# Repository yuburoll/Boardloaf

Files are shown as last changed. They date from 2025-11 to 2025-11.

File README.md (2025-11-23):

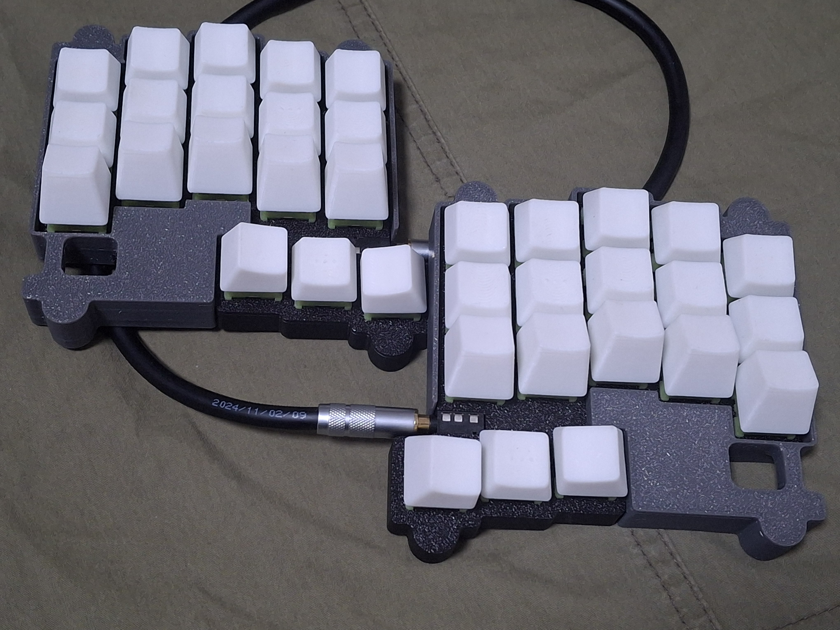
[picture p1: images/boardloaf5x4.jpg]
boardloafImage


# Boardloaf

36 key hotswappable split keyboard in 100x100 pcb

## Preparation

- 2x rp2040 zero (boards formly created by waveshare) (Approx. 4-8$)

- 2x Boardloaf PCB Boards (5 boards are 2$ on JLC w/o shipping cost)

- 1x printed case sets, which you want to make it (4$ for sandwitch, Approx. 12$ if you buy printed one)

- 36x diodes (Approx. 1$)

- (for V1) 32x M2x4 bolts, 16x M2x7 spacers (under 4mm radius) (Approx. 2$)

- (for V2) 16x M2x7 screws, flathead (can use M2x6 or M2x8) (Approx. 1$)

- 2x PJ320A 1/8(3.5mm) TRRS connector (Approx. 1$)

- 1x 1/8(3.5mm) TRRS cable (Approx. 2$, may TRS cable can take the place.)

- 36x MX Keyswitches & Keycaps & MX Hotswap Sockets (Maybe this cost varies too much. 10$ on average)

Approx. 26$-37$(w/o shipping cost) needed to build one.

## Build Guides

work in progress. sorry!

You can see the images in the folder, which uploaded for build guides. Especially you may see how to solder the controller board, because this uses surface mounting by castelated pins.

Images are captured with prototype version PCB, which is different from the current gerber. Current gerber has two "Jump when back side" jumper point on each side, to check which hand is on the position. You may see diode jumper on assembly image for the same role, and you don't need to jump via diodes if you jump jumpers correctly.

This uses [qmk](https://qmk.fm/) to build the firmware. Copy "boardloaf" folder which is in "firmware/qmk" directory to "qmk_firmware\keyboards" folder, and build it via qmk msys.

Or, simply flash uf2 in "uf2Examples" folder by changing rp2040 zero in dfu mode, which can be executed by holding boot button while plugging in usb c. Vial versions are also prepared.

## Licenses

miryoku keymap follows GNU GPL 2.0 license.

all other codes follow MIT license.

all designs and the hardware board follow CC BY-SA 4.0 license.

If you want to make a commercial product, it would be appreciated if you sponsor some bucks for me.

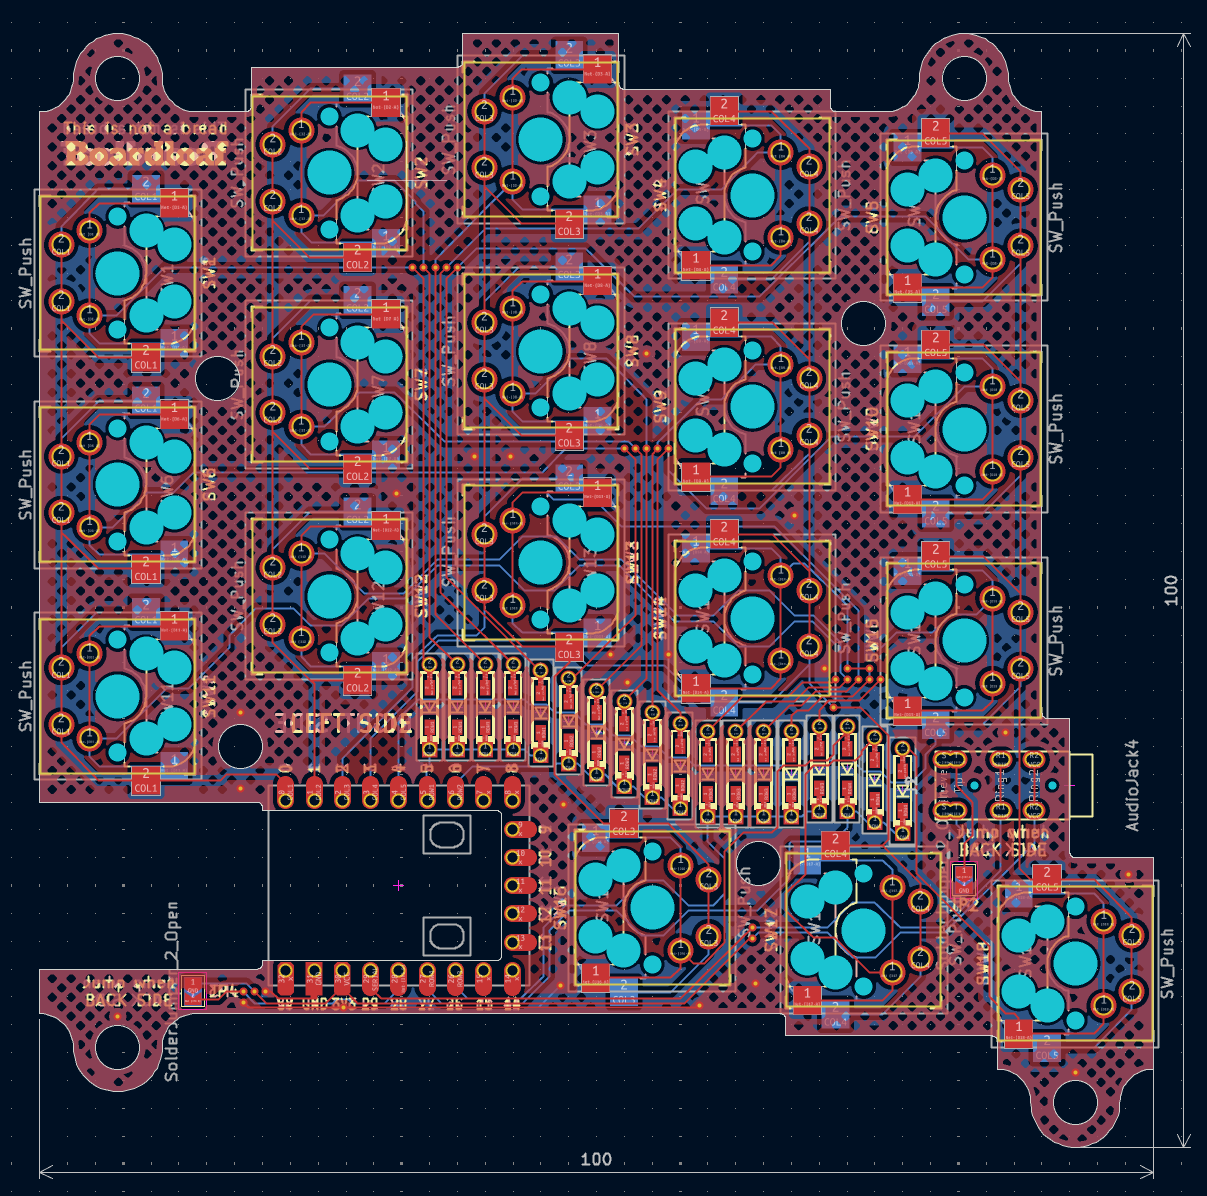
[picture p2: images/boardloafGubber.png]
boardloafGubber


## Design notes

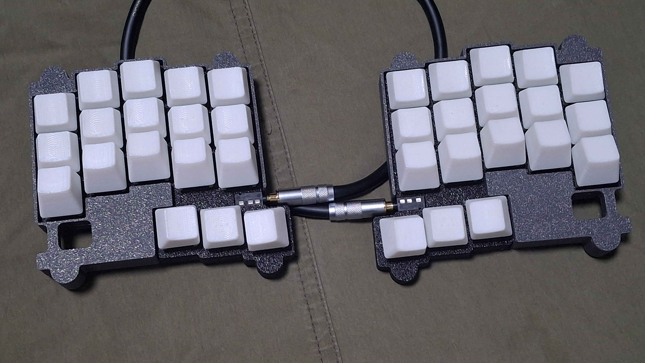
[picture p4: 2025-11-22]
images/boardloaf16x9.jpg

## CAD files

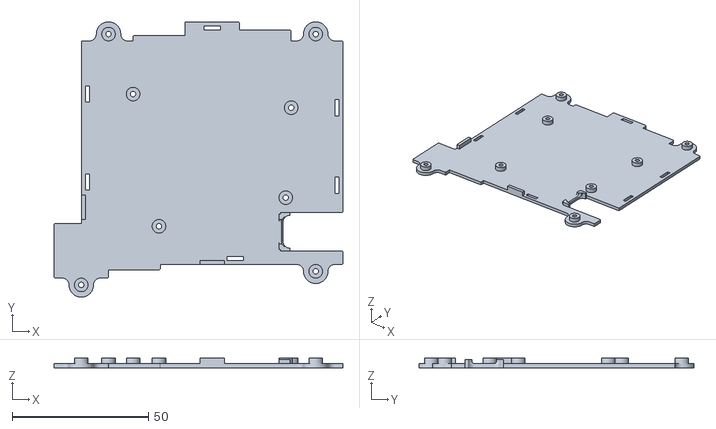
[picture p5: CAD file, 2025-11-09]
case/V2_3dp/BoardloafCaseV2_RDown.stl
106.0 x 101.0 x 3.50

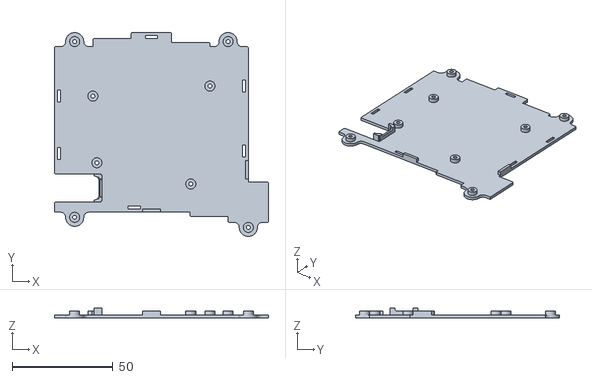
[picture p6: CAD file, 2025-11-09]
case/V2_3dp/BoardloafCaseV2_LDown.stl
106.0 x 101.0 x 5.00

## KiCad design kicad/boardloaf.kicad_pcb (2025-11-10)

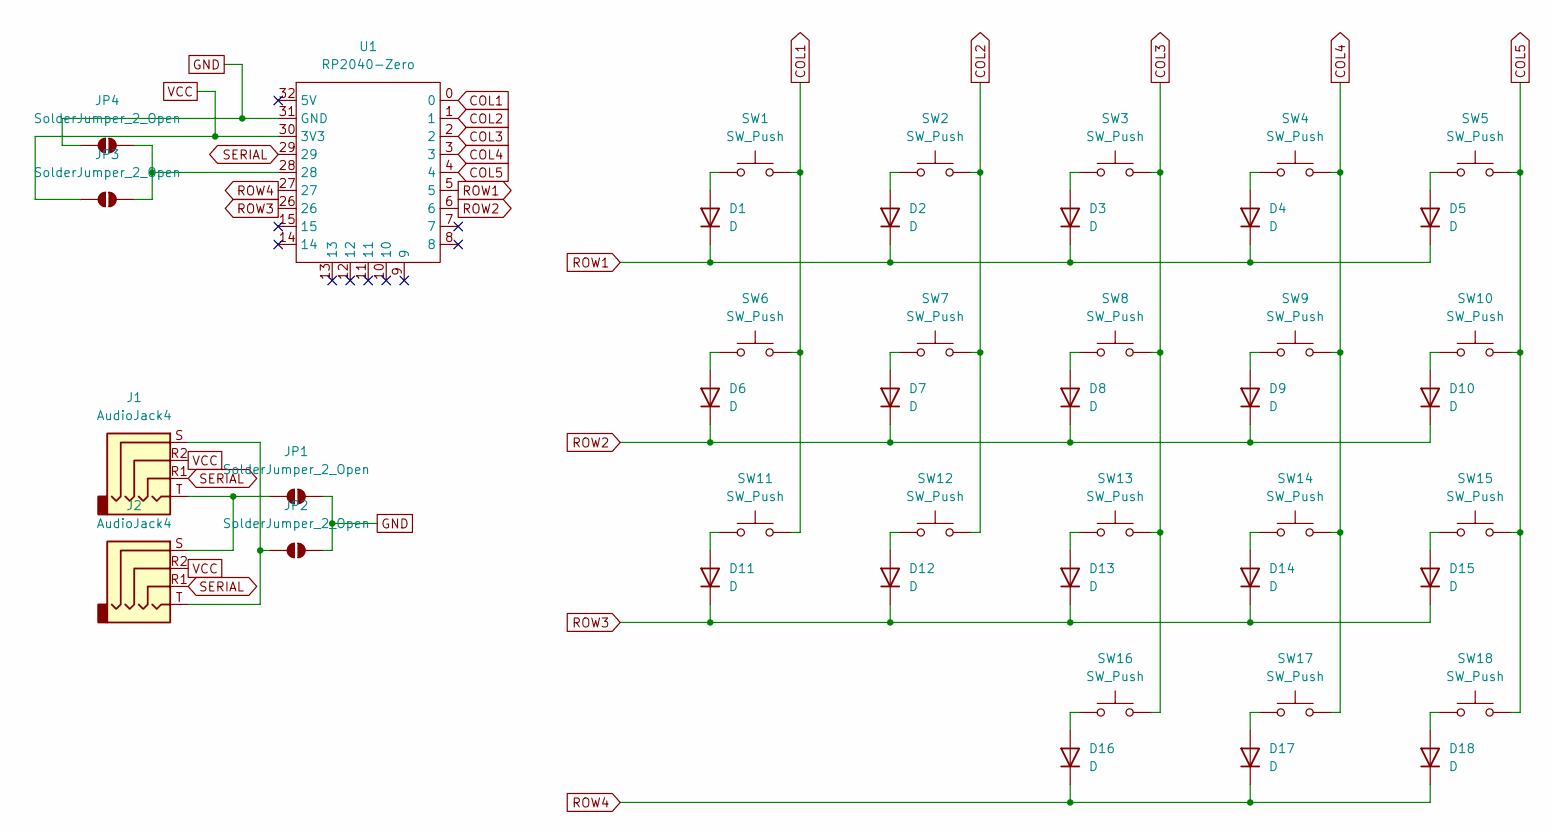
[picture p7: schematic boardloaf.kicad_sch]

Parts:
D1, D2, D3, D4, D5, D6, D7, D8, D9, D10, D11, D12, D13, D14, D15, D16, D17, D18: D
J1, J2: AudioJack4
JP1, JP2, JP3, JP4: SolderJumper_2_Open
SW1, SW2, SW3, SW4, SW5, SW6, SW7, SW8, SW9, SW10, SW11, SW12, SW13, SW14, SW15, SW16, SW17, SW18: SW_Push
U1: RP2040-Zero

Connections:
COL1: SW1.2, SW6.2, SW11.2, U1.0
COL2: SW2.2, SW7.2, SW12.2, U1.1
COL3: SW3.2, SW8.2, SW13.2, SW16.2, U1.2
COL4: SW4.2, SW9.2, SW14.2, SW17.2, U1.3
COL5: SW5.2, SW10.2, SW15.2, SW18.2, U1.4
GND: JP1.2 (B), JP2.2 (B), JP4.1 (A), U1.31 (GND)
unnamed: D1.2 (A), SW1.1
unnamed: D2.2 (A), SW2.1
unnamed: D3.2 (A), SW3.1
unnamed: D4.2 (A), SW4.1
unnamed: D5.2 (A), SW5.1
unnamed: D6.2 (A), SW6.1
unnamed: D7.2 (A), SW7.1
unnamed: D8.2 (A), SW8.1
unnamed: D9.2 (A), SW9.1
unnamed: D10.2 (A), SW10.1
unnamed: D11.2 (A), SW11.1
unnamed: D12.2 (A), SW12.1
unnamed: D13.2 (A), SW13.1
unnamed: D14.2 (A), SW14.1
unnamed: D15.2 (A), SW15.1
unnamed: D16.2 (A), SW16.1
unnamed: D17.2 (A), SW17.1
unnamed: D18.2 (A), SW18.1
unnamed: J1.T, J2.S, JP1.1 (A)
unnamed: J1.S, J2.T, JP2.1 (A)
unnamed: JP3.2 (B), JP4.2 (B), U1.28
ROW1: D1.1 (K), D2.1 (K), D3.1 (K), D4.1 (K), D5.1 (K), U1.5
ROW2: D6.1 (K), D7.1 (K), D8.1 (K), D9.1 (K), D10.1 (K), U1.6
ROW3: D11.1 (K), D12.1 (K), D13.1 (K), D14.1 (K), D15.1 (K), U1.26
ROW4: D16.1 (K), D17.1 (K), D18.1 (K), U1.27
SERIAL: J1.R1, J2.R1, U1.29
VCC: J1.R2, J2.R2, JP3.1 (A), U1.30 (3V3)

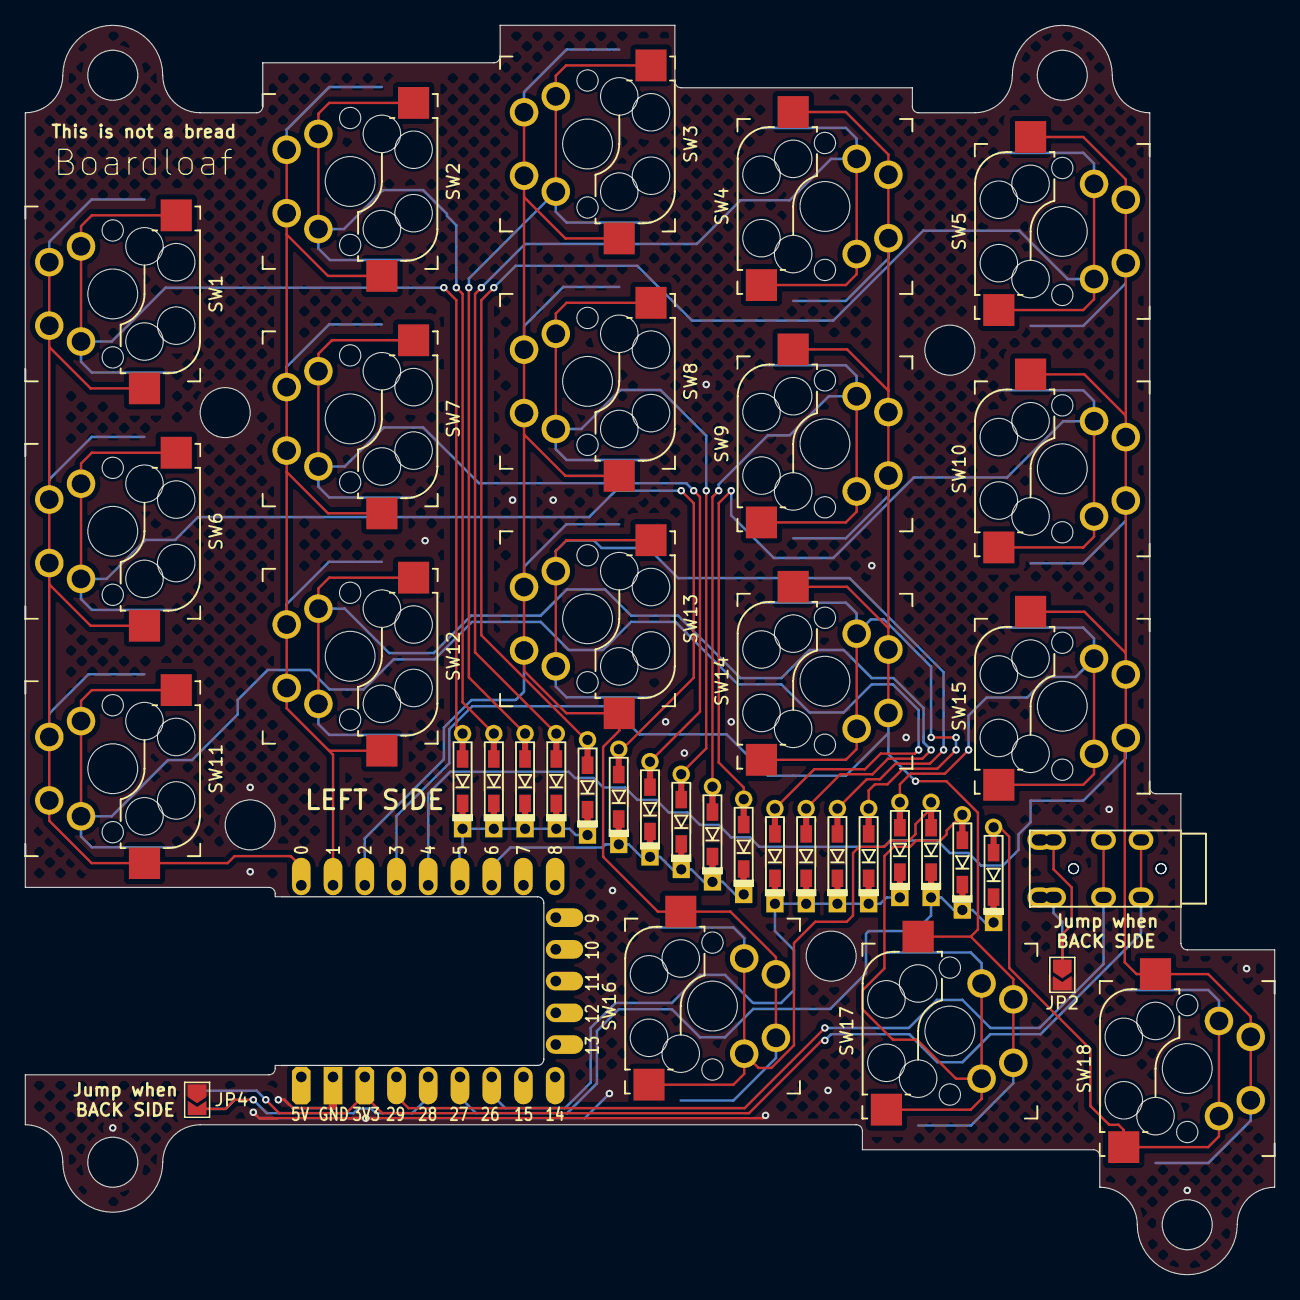
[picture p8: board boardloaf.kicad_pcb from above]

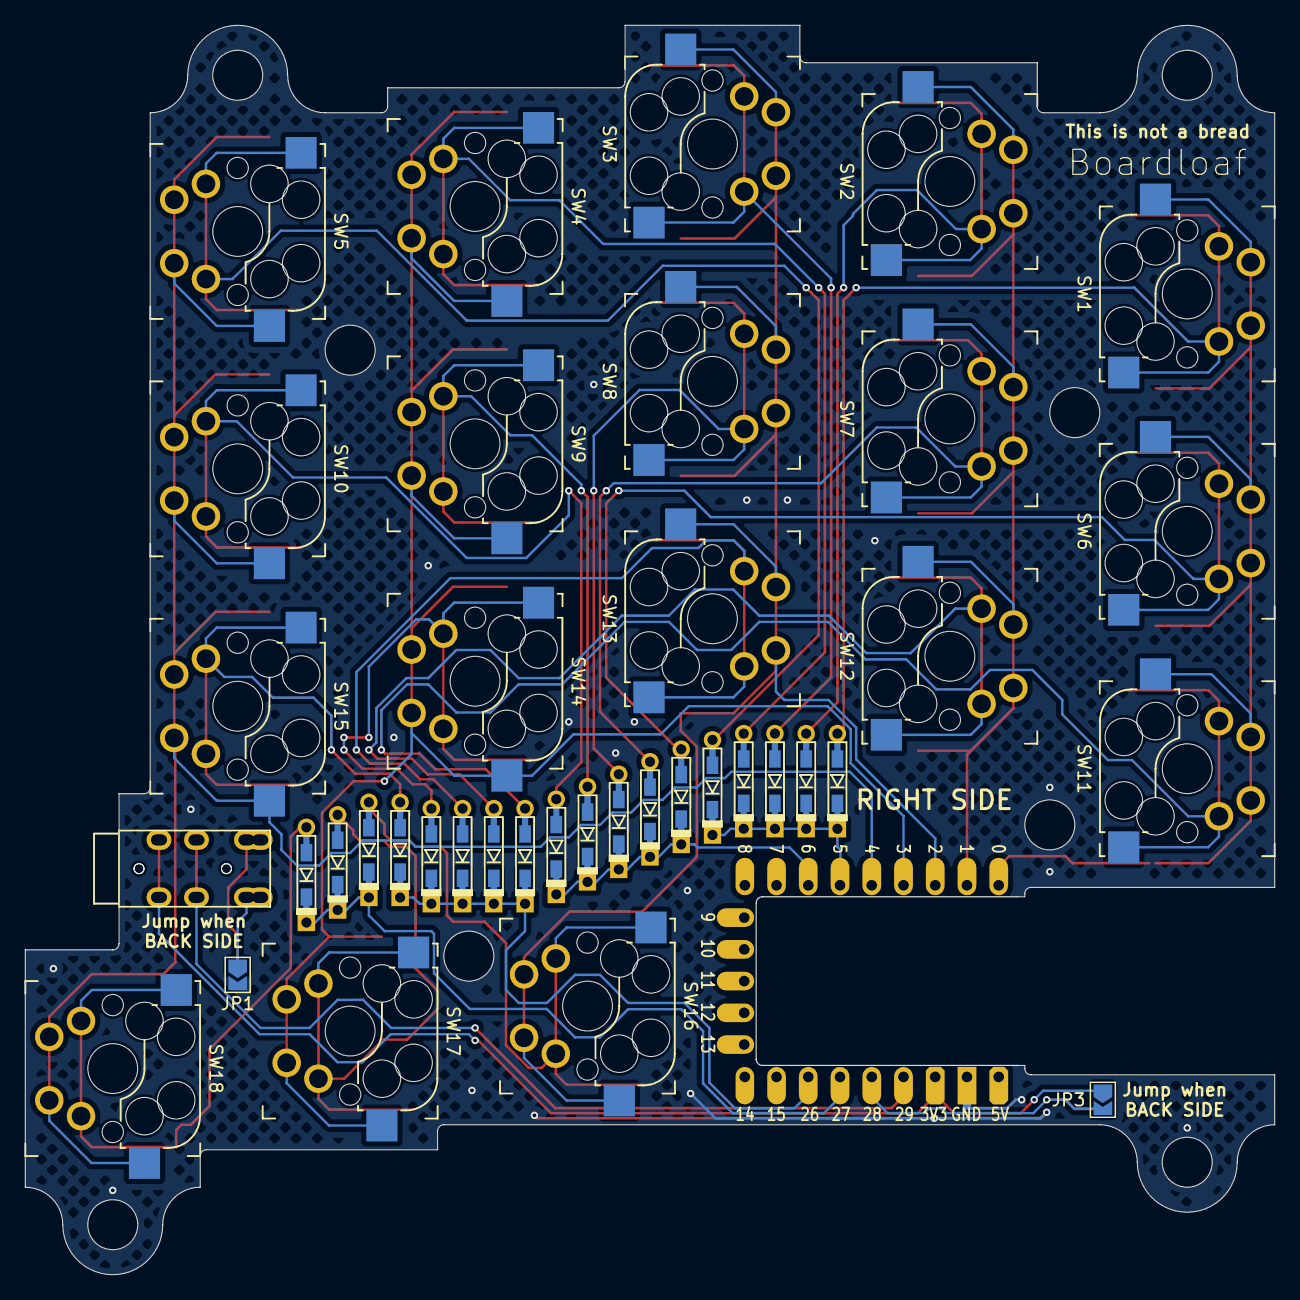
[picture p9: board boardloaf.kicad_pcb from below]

Board: 2 copper layers, 100.0 x 100.0 mm, 43 parts (3 on the bottom side), 33 nets.

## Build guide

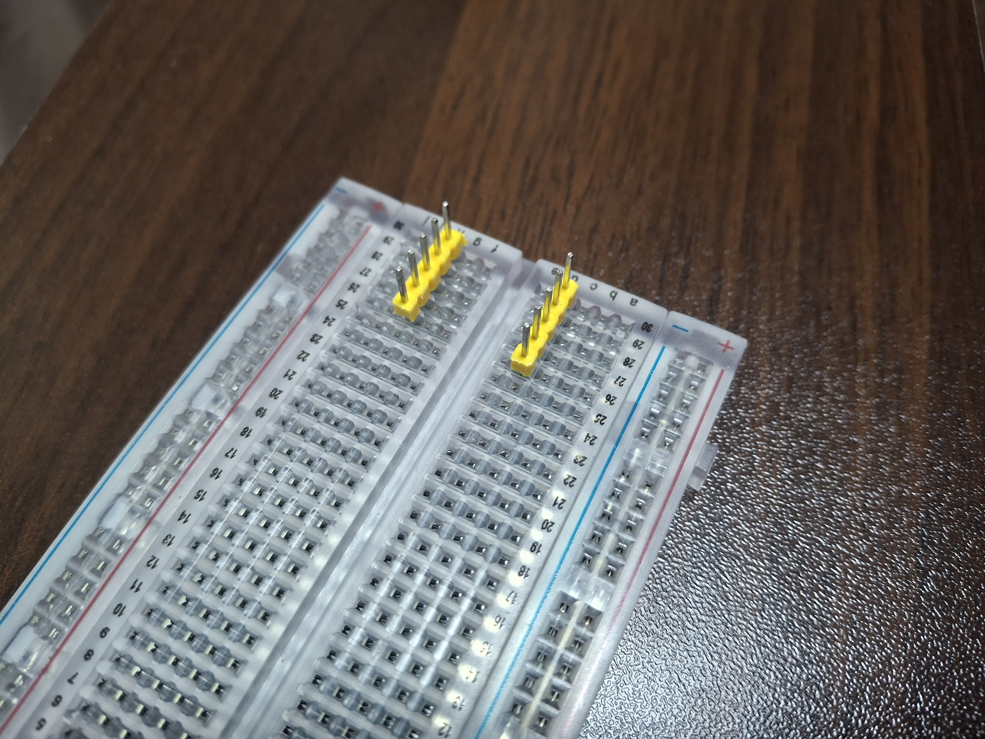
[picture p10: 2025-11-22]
images/boardloafBoardSolder1.jpg

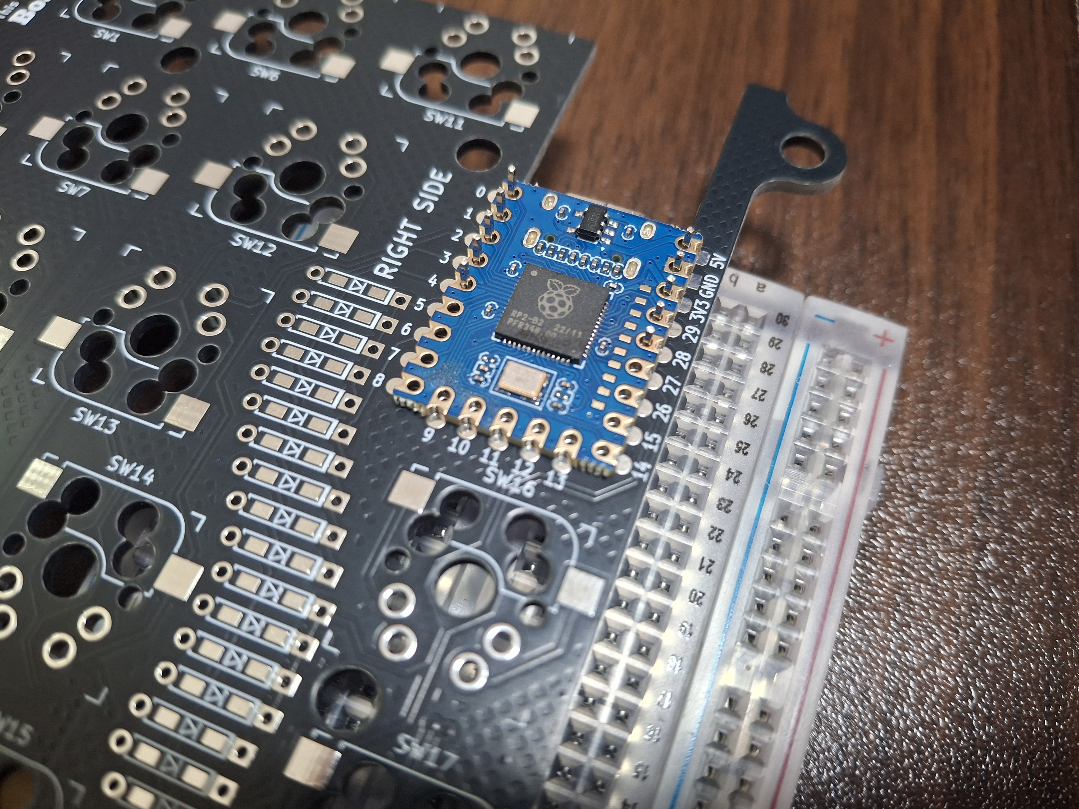
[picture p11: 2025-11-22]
images/boardloafBoardSolder2.jpg

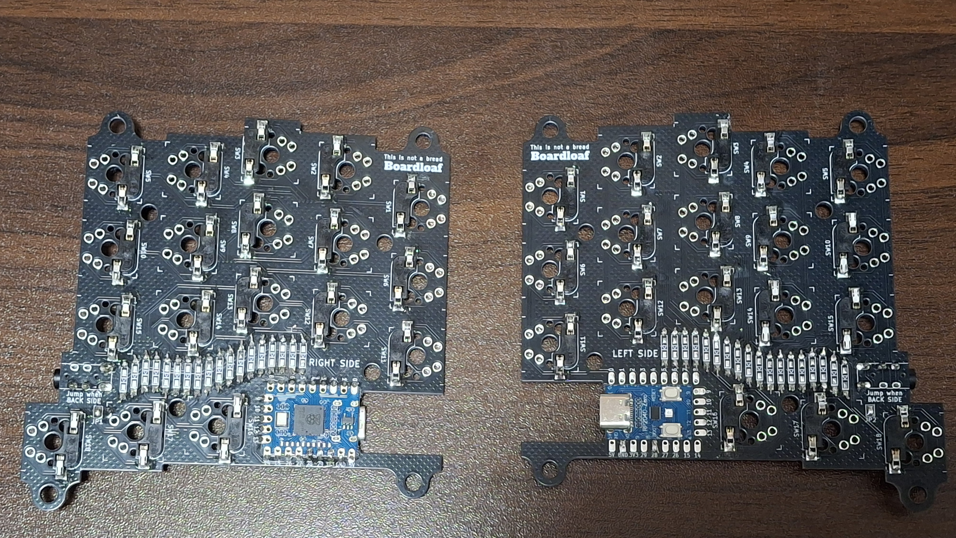
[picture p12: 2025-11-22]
images/boardloafAssembly1.jpg

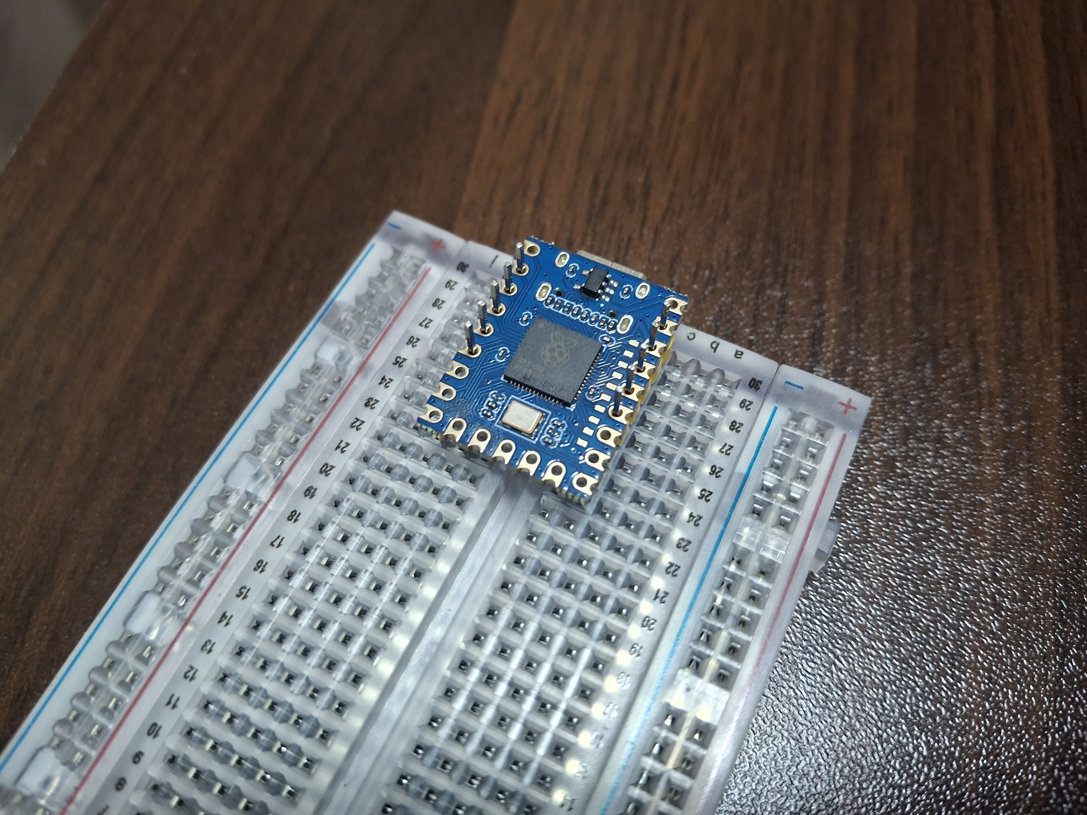
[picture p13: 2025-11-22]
images/boardloafBoardSolder0.jpg

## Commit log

2025-11-04 upload gubberjob and kicad
    [boardloaf-B_Cu.gbr, boardloaf-B_Mask.gbr, boardloaf-B_Paste.gbr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]
2025-11-04 upload backplate
    [boardloaf-TopPlate.kicad_pcb]
2025-11-04 align hole
    [boardloaf-B_Cu.gbr, boardloaf-B_Mask.gbr, boardloaf-B_Paste.gbr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]
2025-11-09 upload printable case
    [BoardloafCaseV2_LDown.stl, BoardloafCaseV2_RDown.stl]
2025-11-09 upload plate case
2025-11-09 change position of case file
    [boardloaf-TopPlate.kicad_pcb]
2025-11-09 made jumper for reverse
    [boardloaf.kicad_pcb, boardloaf.kicad_sch]
2025-11-09 update gubber files
    [boardloaf-B_Cu.gbr, boardloaf-B_Mask.gbr, boardloaf-B_Paste.gbr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]
2025-11-09 get back to once you belong
    [boardloaf.kicad_pcb, boardloaf.kicad_sch]
2025-11-10 fix schema and add jumper
    [boardloaf.kicad_pcb, boardloaf.kicad_sch]
2025-11-10 update gubber
    [boardloaf-B_Cu.gbr, boardloaf-B_Mask.gbr, boardloaf-B_Paste.gbr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]
2025-11-10 update ground route and gubber
    [boardloaf-B_Cu.gbr, boardloaf-B_Mask.gbr, boardloaf-B_Paste.gbr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]
2025-11-20 update case
